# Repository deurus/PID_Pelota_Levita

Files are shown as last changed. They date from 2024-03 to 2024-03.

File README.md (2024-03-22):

# CONTROL DE POSICIÓN DE UNA PELOTA EN LEVITACIÓN

Recientemente, me encontré por casualidad con un vídeo que mostraba cómo un secador de pelo puede hacer levitar una pelota de ping-pong, ilustrando el principio de Bernoulli. Esto despertó mi curiosidad sobre la posibilidad de ajustar la potencia del secador para controlar la altura a la que se mantiene la pelota. Inspirado por esta idea, esa misma noche comencé a experimentar con algunos componentes que tenía guardados y, poco a poco, di forma a la maqueta que les presento hoy. Es un proyecto bastante sencillo de realizar, aunque presenta algunos desafíos a la hora de identificar el sistema. La maqueta consiste en una pelota de ping-pong situada dentro de un tubo, la cual se eleva venciendo la fuerza de la gravedad gracias al aire suministrado por un ventilador.<br>
Las piezas amarillas están impresas en 3D y sirven para asegurar el caudal de aire y conectar el tubo. En la parte superior, el sensor HC-SR04 encaja justo con las dimensiones del diámetro interior del tubo. Si optáis por usar el sensor US-016 deberéis pegarlo con celo o diseñar una pieza para anclarlo.
<p align="center">
  
  
</p>

<h2>Esquema de conexiones</h2>
<p align="center">
  conexiones
</p>

<h2>Esquema de control</h2>
<p align="center">
  
</p>

<h2>Implementación</h2>
<p>Nuestro propósito es posicionar con precisión la pelota en un lugar específico dentro del tubo. Utilizamos un sensor de distancia ultrasónico para medir la distancia exacta de la pelota, expresada en centímetros. A continuación, ajustamos la velocidad de giro del ventilador empleando una señal de modulación de ancho de pulso (PWM, por sus siglas en inglés). Este método nos permite variar finamente la potencia aplicada al ventilador y, por ende, controlar la altura a la que se mantiene la pelota.</p>
https://www.youtube.com/watch?v=kyfIPwP09Ao
<br><br>
Tenéis más información en la entrada del blog:<br>
https://garikoitz.info/blog/2024/03/sintonizar-pid-con-arduino-control-de-posicion-de-una-pelota-en-levitacion/

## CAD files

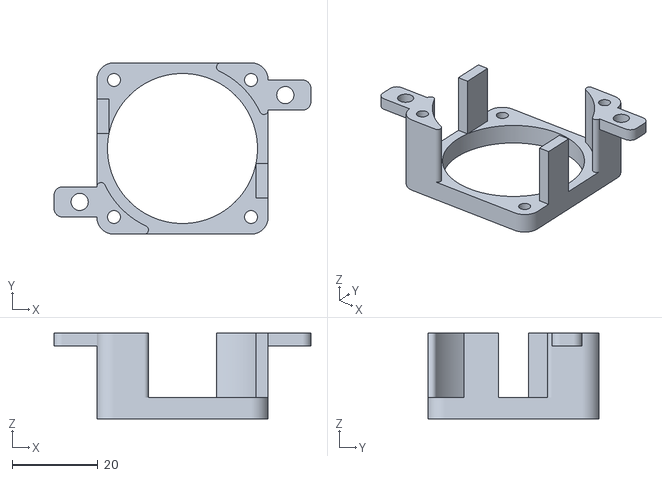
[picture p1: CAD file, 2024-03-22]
3D/40mm - Base.stl
60.0 x 40.0 x 20.0

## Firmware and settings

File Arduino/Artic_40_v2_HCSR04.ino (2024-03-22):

/***************************************************************
* Control de posición de una pelota en levitación V0.2
* Desarrollado por Garikoitz Martínez [garikoitz.info] [03/2024]
* https://garikoitz.info/blog/?p=2215
***************************************************************/
/***************************************************************
* Librerías
***************************************************************/
#include <PID_v1.h>
/***************************************************************
* Variables
***************************************************************/
const int trigPin = 5;
const int echoPin = 6;
float distancia = 0;
float distancia_Ant = 0;
float distancia_Clamp = 0;
float distanciaFilter;
long duracion = 0;
int Ts = 100; //Sample time in ms
unsigned long previousMillis = 0;
double alpha = 0.4; //Filtro EMA
//Ventilador
float ZC1_PV = 0.0;
float ZC1_SP = 0.0;
int ZC1_OP = 0;
int ZC1SPMIN = 10;
int ZC1SPMAX = 22;
int ZC1OPMIN = 0;
int ZC1OPMAX = 100;
int valorPWM = 0;
// global variables
const char sp = ' ';           
const char nl = '\n';
boolean newData = false; 
char Buffer[64]; 
int buffer_index = 0; 
String cmd;  
float val;
/***************************************************************
* Sintonías calculadas -> Integrador
* Test -> APV = 3% | AOP = 3% | T0 = 1.2s
* v = 2.5 | Kv = 2.08 | T0 = 1.2
* KcZC1=0.69, KiZC1=0.29, KdZC1=0.41; (Sintonía inicial)
***************************************************************/
double SetpointZC1, InputZC1, OutputZC1;
double KcZC1=0.69, KiZC1=0.29, KdZC1=0.41; 
PID PIDZC1(&InputZC1, &OutputZC1, &SetpointZC1, KcZC1, KiZC1, KdZC1, P_ON_E, REVERSE);    //PI-D //DIRECT //REVERSE
//PID PIDZC1(&InputZC1, &OutputZC1, &SetpointZC1, KcZC1, KiZC1, KdZC1, P_ON_M, REVERSE);  //I-PD
/***************************************************************
* SETUP
***************************************************************/ 
void setup() {
  while (!Serial) {
    // wait for serial port to connect.
  }
  Serial.begin(9600);
  pinMode(9, OUTPUT); // Configura el pin 9 como salida
  valorPWM = 0;
  // Configuración del Timer1 para PWM a 25 kHz
  TCCR1A = _BV(COM1A1) | _BV(WGM11); // Modo de comparación no invertido y modo Fast PWM
  TCCR1B = _BV(WGM13) | _BV(WGM12) | _BV(CS10); // Sin preescalado y modo Fast PWM
  ICR1 = 639; // Establece el TOP para obtener 25 kHz = 639
  OCR1A = 0; // Inicializa el ciclo de trabajo en 0
  /*
   * ICR1 = ((Frecuencia_CPU) / (Frecuencia PWM deseada * preescalado)) - 1
   * Ejemplo para 20 kHz
   * ICR1 = (16000000 Hz / 20000 Hz * 1) - 1 = 799
   */
  pinMode(trigPin, OUTPUT);
  pinMode(echoPin, INPUT);
  //
  previousMillis=0;
  PIDZC1.SetOutputLimits(0, 255);
  PIDZC1.SetMode(MANUAL);
  if (Ts < 100){
    PIDZC1.SetSampleTime(Ts);
  }
  distancia = medirDistancia();
}
/***************************************************************
* BUCLE PRINCIPAL
***************************************************************/
void loop() {
  if (millis() - previousMillis > Ts)
  {
    distancia = medirDistancia();
    distancia = constrain(distancia, 0, 26);
    distanciaFilter = alpha*distancia+(1.0-alpha)*distanciaFilter; //Filtro EMA
    ZC1_PV = distanciaFilter;
    //ZC1_PV = map(distanciaFilter, 0, 26, 26, 0);
    //ZC1_PV = map(distanciaFilter, 4, 26, 0, 100); //cm -> %
    distancia_Ant = distancia;
    
    previousMillis = millis();
    //Funciones Lectura/Escritura Serial
    LeoCMD();
    ProcesoCMD();
    EjecutoCMD();
    //PID (Parámetros vía serial cmds)
    if (PIDZC1.GetMode() == 1){//AUTO
        InputZC1 = ZC1_PV;
        SetpointZC1 = ZC1_SP;
        PIDZC1.Compute();
        OCR1A = map(OutputZC1, 0, 255, 0, ICR1);
        ZC1_OP = map(OutputZC1, 0, 255, 0, 100); //PWM -> %
     }else if (PIDZC1.GetMode() == 0) {//MANUAL
    /*>>INICIALIZACIÓN<< -> para evitar problemas al pasar de MANUAL a AUTO
    (1) --> PV Tracking -> igualamos SP a PV
    (2) --> Calculamos la salida de control para que 'inicialice' correctamente el PID sin provocar saltos bruscos al pasar de Manual a Auto.
    */
        ZC1_SP = ZC1_PV; //(1)
        OCR1A = map(OutputZC1, 0, 255, 0, ICR1);
        OutputZC1 = map(ZC1_OP, 0, 100, 0, 255); //(2)
     }
     //Para Arduino COM Plotter
     Serial.print("#");        //Char inicio
     Serial.print(ZC1_SP,0);    //Serial.print(ZC1_SP,0);
     Serial.write(" ");        //separador
     Serial.print(ZC1_PV,0);    //
     Serial.write(" ");        //separador
     Serial.print(ZC1_OP);      //
     Serial.println();
    //
  }//millis
}//loop
/***************************************************************
* FUNCIONES
***************************************************************/
//No hace falta tocar
void LeoCMD() {
  while (Serial && (Serial.available() > 0) && (newData == false)) {
    int byte = Serial.read();
    if ((byte != '\r') && (byte != nl) && (buffer_index < 64)) {
      Buffer[buffer_index] = byte;
      buffer_index++;
    }
    else {
      newData = true;
    }
  }   
}
//No hace falta tocar
void ProcesoCMD(void) {
  if (newData) {
    String read_ = String(Buffer);
    // separate command from associated data
    int idx = read_.indexOf(sp);
    cmd = read_.substring(0, idx);
    cmd.trim();
    cmd.toUpperCase();
    // extract data. toFloat() returns 0 on error
    String data = read_.substring(idx + 1);
    data.trim();
    val = data.toFloat();
    // reset parameter for next command
    memset(Buffer, 0, sizeof(Buffer));
    buffer_index = 0;
    newData = false;
  }
}
//A partir de aquí comandos personalizados
float medirDistancia() {
  digitalWrite(trigPin, LOW);// Limpiar el pin trig
  delayMicroseconds(2);
  digitalWrite(trigPin, HIGH);// Configurar el pin trig en HIGH por 10 microsegundos
  delayMicroseconds(10);
  digitalWrite(trigPin, LOW);
  duracion = pulseIn(echoPin, HIGH);// Leer el tiempo de duración del eco
  distancia = duracion * 0.017;// Calcular la distancia * 0.034 * 0.5
  if(duracion>1600 || duracion < 200){
    //Fuera de rango. Depende de si invertimos la PV será 4 ó 26, en este caso.
    distancia = distancia_Clamp;
  }else{
    return distancia;
  }
}
void EjecutoCMD(void) {
  if (cmd == "ZC1A") {
    PIDZC1.SetMode(AUTOMATIC);
  }
  else if (cmd == "ZC1M") {
    PIDZC1.SetMode(MANUAL);
  }
  else if (cmd == "ZC1SP") {
    if (PIDZC1.GetMode() == 1){
      if (val > ZC1SPMAX){
        val = ZC1SPMAX;
      }
    if (val < ZC1SPMIN){
        val = ZC1SPMIN;
      }
    ZC1_SP = val;
    }
  }
  else if (cmd == "ZC1OP") {
    if (PIDZC1.GetMode() == 0){
      if (val > ZC1OPMAX){
        val = ZC1OPMAX;
      }
      if (val < ZC1OPMIN){
        val = ZC1OPMIN;
      }
      ZC1_OP = val;
      //map(value, fromLow, fromHigh, toLow, toHigh)
      val = map(val, 0, 100, 0, 255);
      OCR1A = map(OutputZC1, 0, 255, 0, ICR1);
    }
  }
  else if (cmd == "ZC1KC") {
    PIDZC1.SetTunings(val,KiZC1,KdZC1);
  }
  else if (cmd == "ZC1KI") {
    PIDZC1.SetTunings(KcZC1,val,KdZC1);
  }
  else if (cmd == "ZC1KD") {
    PIDZC1.SetTunings(KcZC1,KiZC1,val);
  }
  else if (cmd == "FILTRO") {
    if (val > 1){
        val = 1;
    }
    if (val <= 0){
        val = 0.01;
    }
    alpha = val;
  }
  else if (cmd == "ZC1FR") {
    ICR1 = val;
  }
  Serial.flush();
  cmd = "";
}
